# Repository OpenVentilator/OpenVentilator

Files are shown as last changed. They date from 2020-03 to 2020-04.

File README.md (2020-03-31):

# Open Ventilator
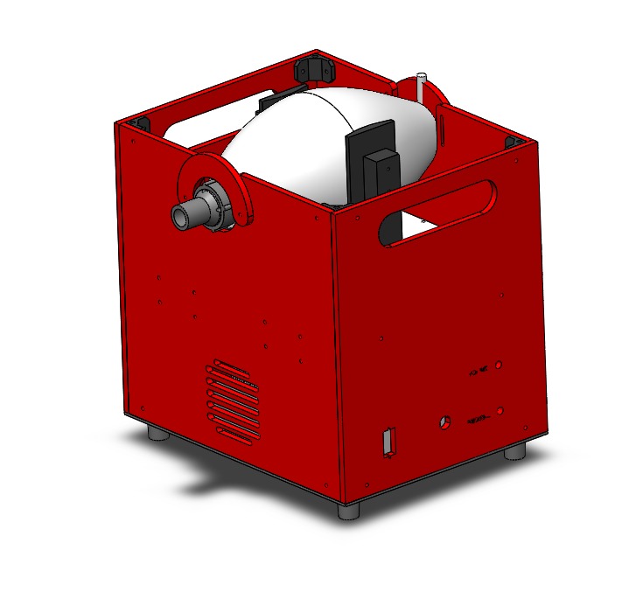
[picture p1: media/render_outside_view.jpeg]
Outside View

The open ventilator project was created in response to the demand for respirator created by the COVID-19 epidemic. The aim of the project is to create respiratory support device that can be quickly and easily produced with locally sourced material. The device is not a replacement for for respirators but in the event of a shortage of ventilators, these devices can provide support to patients that would otherwise not have any.

## Features

After consulting anesthesiologists, pulmonologists and biomedical engineers, we have settled for the below minimum feature set:

| Feature | Values |
|---|---|
| Configurable Respiratory Rate (RR) | 8-24 BPM |
| Configurable Tidal Volume (TD) | Up to 600cc |
| Configurable Fraction of Inhaled Oxygen (fio2) | Up to 100% |
| Positive End Expiratory Pressure (PEEP) | 1.5-20 H2O cm |
| Maximum Presspure | 4.0 kpa |
| Airway Pressure Monitor | 0-60 cmH2Ox |
| Exhaled air filtering | HEPA |

Several documents have been published with similar specs, notably the [Rapidly manufactured ventilator system specification published by the Department of Health and Social Care in the UK](https://www.gov.uk/government/publications/coronavirus-covid-19-ventilator-supply-specification/rapidly-manufactured-ventilator-system-specification)

### Design Approach

Our approach was to reuse existing, tested and widely available technologies where possible. We also relied on previous research done notably at MIT and Rice University to develop our design.

We settled on a BVM based design based on their availabilty and familiarity and on the available add ons that provide many of the target features.

### Air Circuit
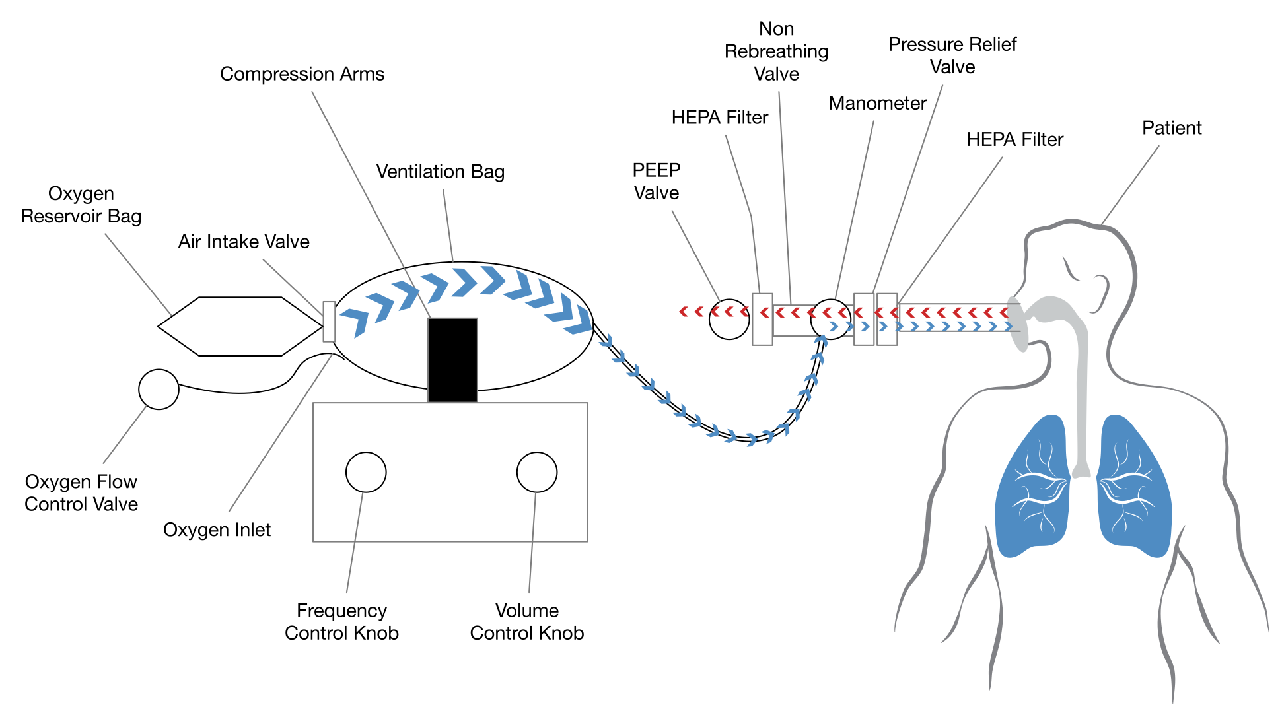
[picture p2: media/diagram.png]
Ventilator Diagram


The design in its current form implements a Mapleson A (Magill) breathing circuit. In order to achieve that, we moved the non rebreathing valve from the bag to the end of the tube. We have designed a 3D printed adaptor to connect the tube to the bag. 

### Board
To speed up go to market, we have reused an existing propriatory board we have in stock. Hence there are no schematics for the board in this repository. A dedicated open source board needs to be designed and published.

### Todo
- Publish images, renders and videos
- Publish BOM
- Design and publish logic board

### LICENSE

The design is released under a CERN Open Hardware License

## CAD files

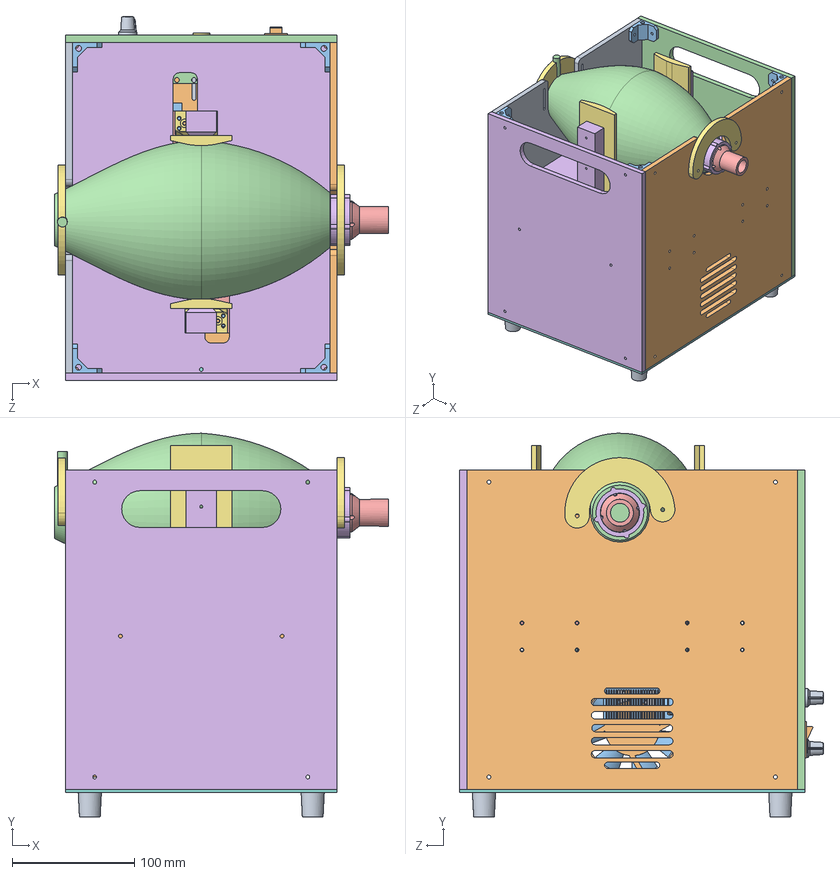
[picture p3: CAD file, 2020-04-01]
hardware/respirate_mechanism.SLDASM
273.0 x 313.3 x 297.2 mm
instrument ball bearing_68_iso x 4
motor_holder
roulement_guides x 4
limit_switch
spacerlong x 4
top_chassis_plate
pusher_holder x 2
spacershort x 4
side_cover_big
side_cover
bracket x 8
side_cover_2
spur_gear_copu x 2
side_cover_2_bis
holder_bag x 2
spur gear_iso_10 x 3
lower_gearbox_plate
Base
Cuerpo
Tapa
Eje
pusher x 2
pusher_accee x 2
lower_plate
rubber_supports x 4
Fan_HouseKD1208PTS3_KD1208PTS3
FanKD1208PTS3_KD1208PTS3
pcb
spacer15mm x 4
stepstick x 2
0402CAP_CAP0402CAP x 12
1206_CAP1206 x 2
QFN28ET_A4983 x 2
0402RES_RESISTOR0402RES x 8
0805_RESISTOR x 4
TRIMPOT3MM_TRIMPOTSMD x 2
Pin header pitch 2.54mm_08 contacts x 4
Heatsink For A4988 x 2
Motor Driver x 3
atmega2560
tactile_switch_smd
resonator16mhz
connector_8_pins x 3
connector_2_pins x 4
connector_5_pins x 3
connector_6_pins
connector_3_pins x 6
connector_4_pins x 5
pan head cross recess screw_iso x 4
mks-tb6600
AMBU_BAG
ambu_adaptor_part1
ambu_adaptor_part2
dc_connector
Knob-4 x 2
switch

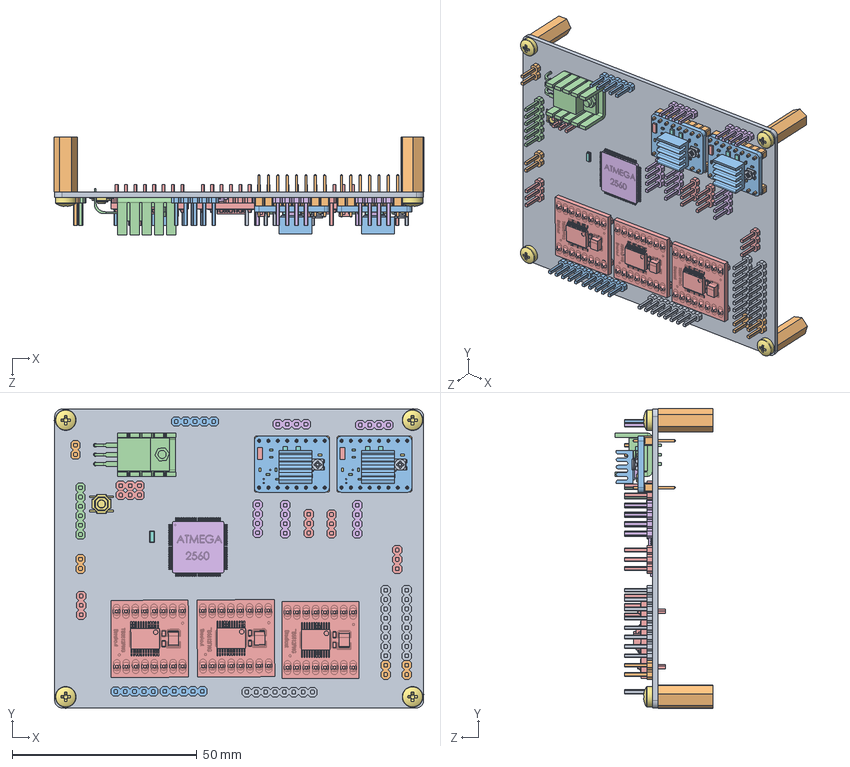
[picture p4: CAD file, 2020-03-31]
hardware/board.SLDASM
100.3 x 81.3 x 26.7 mm
pcb
spacer15mm x 4
stepstick x 2
0402CAP_CAP0402CAP x 12
1206_CAP1206 x 2
QFN28ET_A4983 x 2
0402RES_RESISTOR0402RES x 8
0805_RESISTOR x 4
TRIMPOT3MM_TRIMPOTSMD x 2
Pin header pitch 2.54mm_08 contacts x 4
Heatsink For A4988 x 2
Motor Driver x 3
atmega2560
tactile_switch_smd
resonator16mhz
connector_8_pins x 3
connector_2_pins x 4
connector_5_pins x 3
connector_6_pins
connector_3_pins x 6
connector_4_pins x 5
pan head cross recess screw_iso x 4

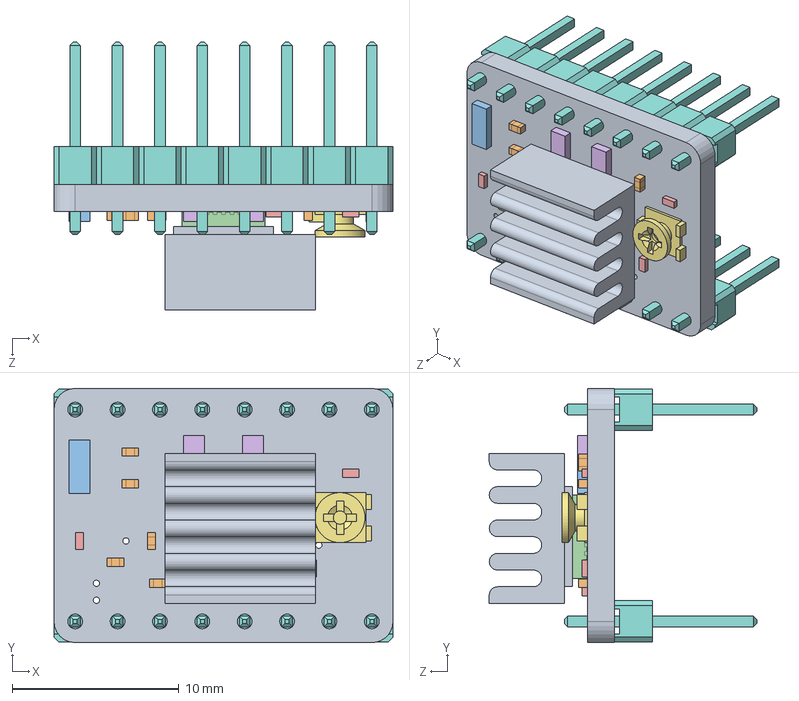
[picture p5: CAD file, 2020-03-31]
hardware/stepper_motor_driver.SLDASM
20.3 x 15.2 x 16.0 mm
stepstick
0402CAP_CAP0402CAP x 6
1206_CAP1206
QFN28ET_A4983
0402RES_RESISTOR0402RES x 4
0805_RESISTOR x 2
TRIMPOT3MM_TRIMPOTSMD
Pin header pitch 2.54mm_08 contacts x 2
Heatsink For A4988

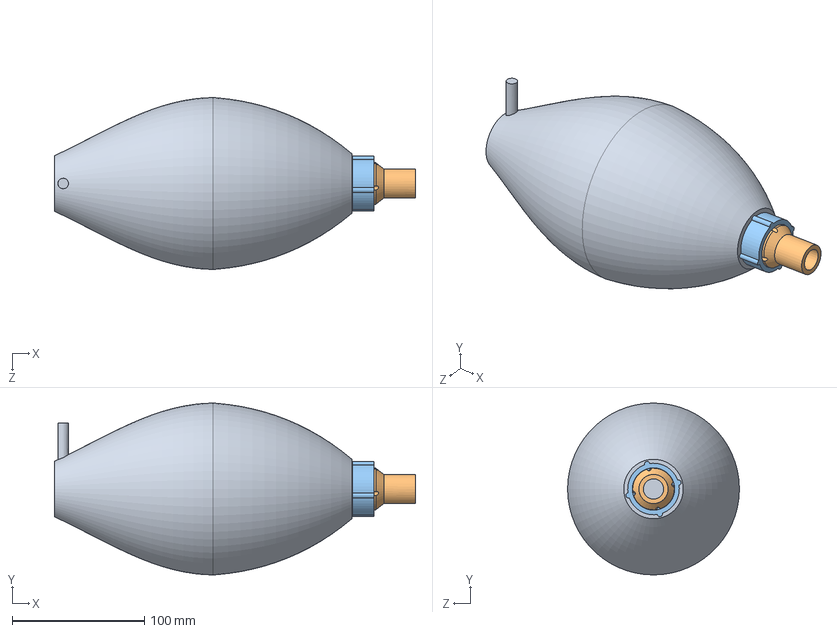
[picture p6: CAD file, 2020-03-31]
hardware/AMBU_Assembly.SLDASM
273.0 x 130.0 x 130.0 mm
AMBU_BAG
ambu_adaptor_part1
ambu_adaptor_part2

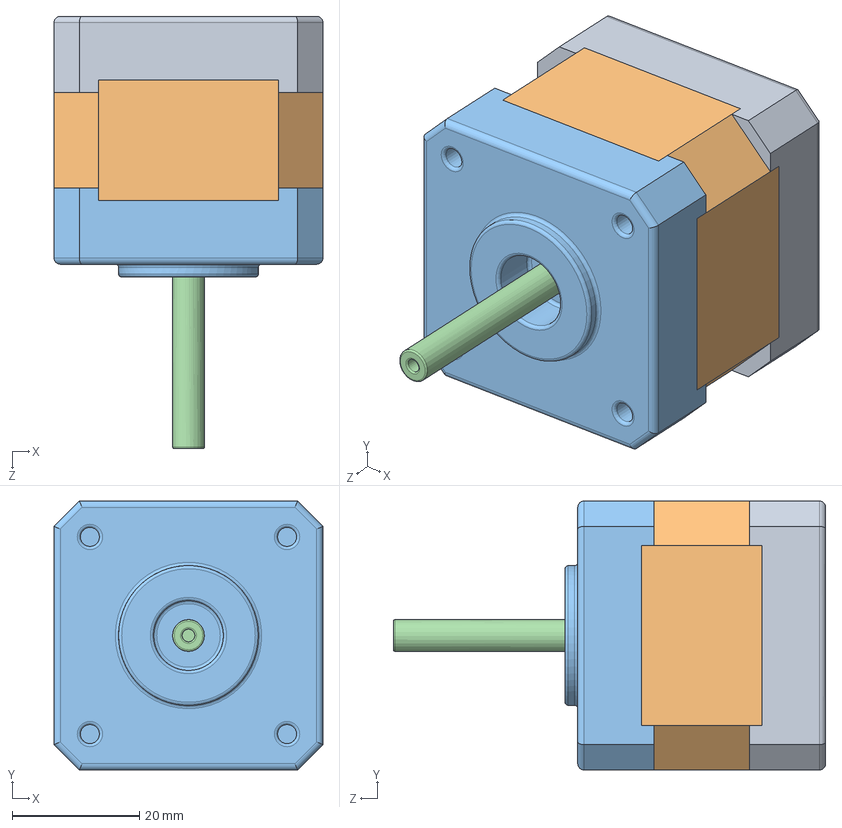
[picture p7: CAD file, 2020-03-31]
hardware/NEMA 17 with T5 Pulley.SLDASM
42.3 x 42.3 x 68.0 mm
Base
Cuerpo
Tapa
Eje

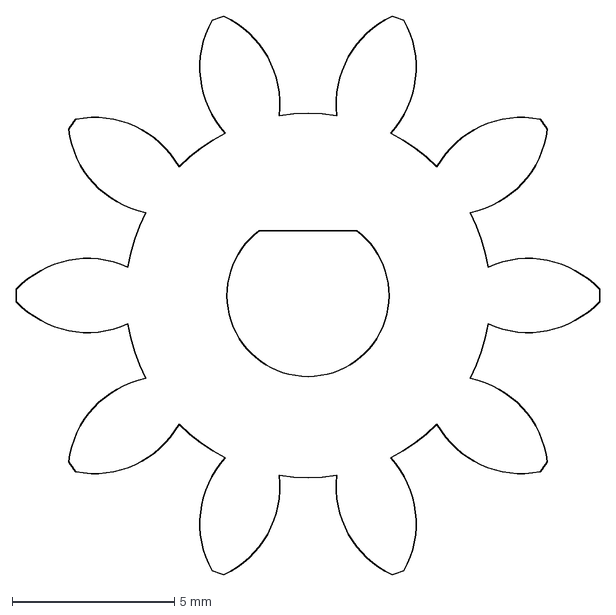
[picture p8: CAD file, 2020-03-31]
hardware/Gears_DXF/spur_gear_10X2.DXF
18.0 x 17.2 mm

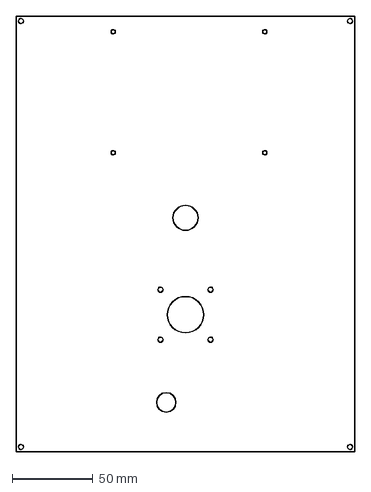
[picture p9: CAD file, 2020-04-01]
hardware/PLEXI_DXF/lower_gearbox_plate.DXF
210.0 x 270.0 mm

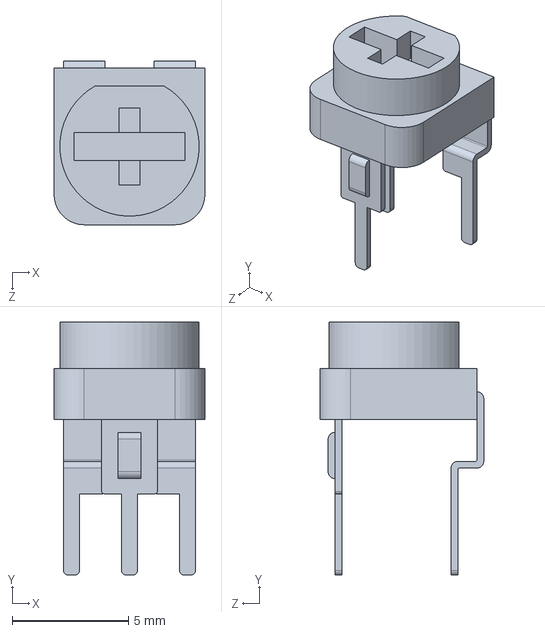
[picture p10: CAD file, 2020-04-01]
hardware/Pot - RES_VAR1.sldprt
6.50 x 10.9 x 7.05 mm

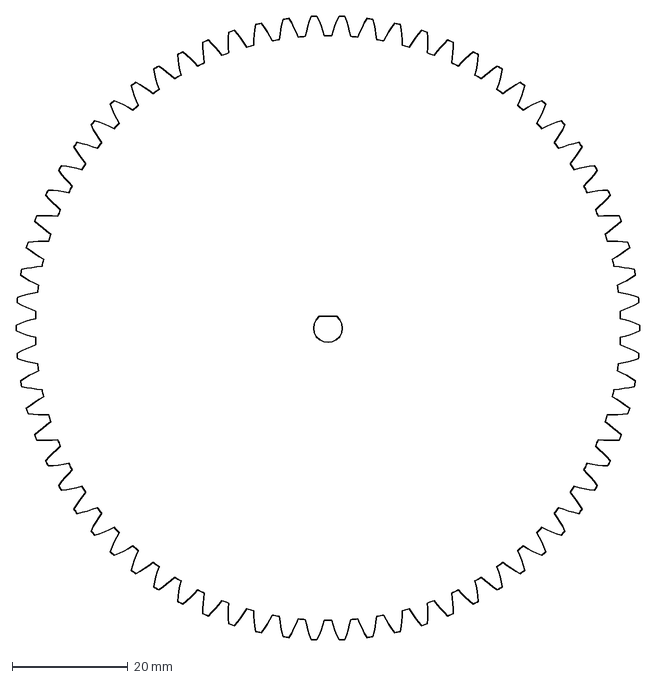
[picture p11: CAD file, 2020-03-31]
hardware/Gears_DXF/spur_gear_70.DXF
108.0 x 107.9 mm

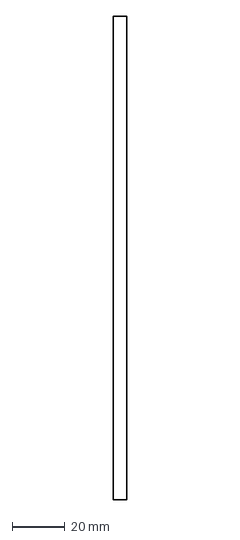
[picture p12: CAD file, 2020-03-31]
hardware/PLEXI_DXF/roulement_guides_slim.DXF
5.21 x 182.6 mm

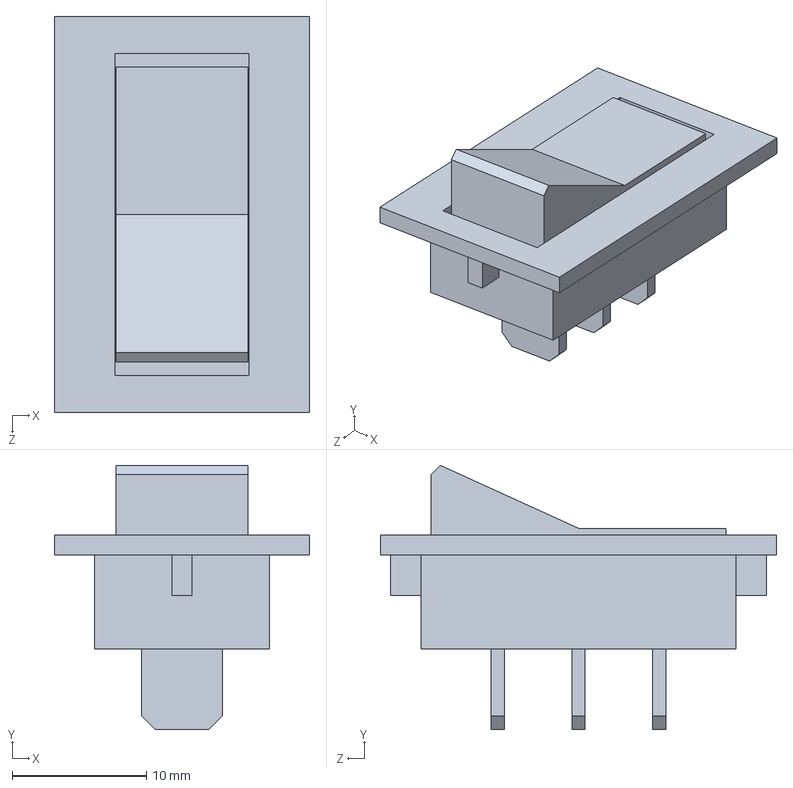
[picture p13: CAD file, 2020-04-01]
hardware/switch.SLDPRT
19.0 x 19.7 x 29.5 mm

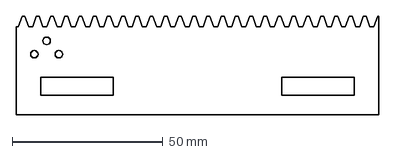
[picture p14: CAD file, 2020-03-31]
hardware/Gears_DXF/rackX2.DXF
120.0 x 32.5 mm

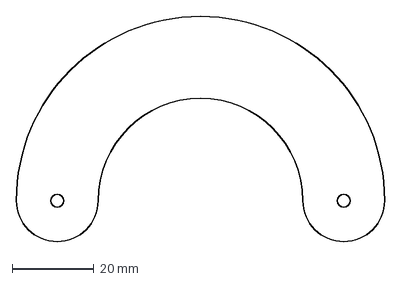
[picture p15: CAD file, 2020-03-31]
hardware/PLEXI_DXF/holder_bag.DXF
90.0 x 55.0 mm

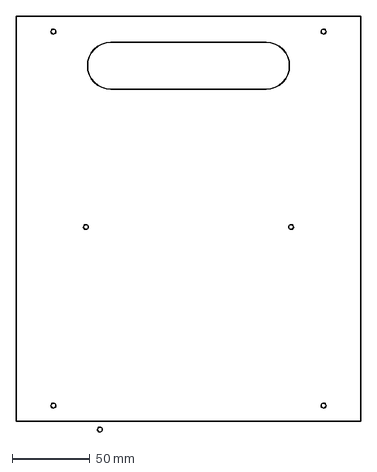
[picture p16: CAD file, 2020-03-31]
hardware/PLEXI_DXF/side_cover_2_bis.DXF
222.0 x 267.7 mm

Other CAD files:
hardware/Knob-4.sldprt
hardware/PLEXI_DXF/lower_plate.DXF
hardware/lower_gearbox_plate.SLDPRT
hardware/PLEXI_DXF/side_cover.DXF
hardware/0402CAP_CAP0402CAP.sldprt
hardware/0402RES_RESISTOR0402RES.sldprt
hardware/0805_RESISTOR.sldprt
hardware/1206_CAP1206.sldprt
hardware/67898.SLDPRT
hardware/7805.SLDPRT
hardware/AMBU_BAG.SLDPRT
hardware/Base.SLDPRT
hardware/Cuerpo.SLDPRT
hardware/Eje.SLDPRT
hardware/FanKD1208PTS3_KD1208PTS3.sldprt
hardware/Fan_HouseKD1208PTS3_KD1208PTS3.sldprt
hardware/Heatsink For A4988.sldprt
hardware/KD1208PTS3.SLDASM
hardware/KD1208PTS3.step
hardware/Motor Driver.SLDPRT
hardware/PLEXI_DXF/motor_holder.DXF
hardware/PLEXI_DXF/roulement_guides.DXF
hardware/PLEXI_DXF/side_cover_2.DXF
hardware/PLEXI_DXF/side_cover_big.DXF
hardware/PLEXI_DXF/spacerlong.DXF
hardware/PLEXI_DXF/spacershort.DXF
hardware/PLEXI_DXF/top_chassis_plate.DXF
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

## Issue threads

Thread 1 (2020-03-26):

Reinforce arms platform

OpenVentilator, 2020-03-26:
As suggested by Paul Abi Nasr on this slack thread, time fatigue might break this piece and needs to be reinforced.

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

https://nerds-leb.slack.com/archives/C01013DQRHQ/p1585160358016100

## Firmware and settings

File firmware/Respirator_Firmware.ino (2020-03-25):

#include <Stepper.h>
#include <EEPROM.h>
#include <math.h>
#include "STEPPER.H"

///////////////Stepper///////////////// 
STEPPER _S   = {1,22,LOW,24,LOW,25,16,0,0,480,0};          
///////////////Stepper/////////////////

int show_logs = HIGH;

int frequency_pin = A1;
int freq = 0;
int Volume_pin = A0;
int vol = 0;

int max_travel = 3500;
int min_travel = 600;

void setup() 
{
    Serial.begin(9600); 
    _init_steppers();
    home_stepper(&_S,_S._speed,_S._speed);  

    freq  = read_frequency_knob () ; 
    vol = read_volume_knob ();
     
    Serial.print("VOLUME: "); Serial.println(read_volume_knob ());
    Serial.print("FREQ: "); Serial.println(read_frequency_knob ());
    delay(50);
}


void test_stepper()
{
    if(Serial.available()>0)
    {
         int x = Serial.parseInt();
       
         if ( x >=0 )
         {
             run_stepper( &_S,  x );
         }
         else 
         {
             home_stepper(&_S, _S._speed ,_S._speed/2);
         }

         while (Serial.available()>0)
         {
             Serial.read();
         }
    }
}

void loop() 
{    
     freq  = read_frequency_knob () ; 
     vol = read_volume_knob ();
     
     Serial.print("VOLUME: "); Serial.println(read_volume_knob ());
     Serial.print("FREQ: "); Serial.println(read_frequency_knob ());
     delay(50);

           
     long timer1 = millis();
     if(vol ==1 ) run_stepper( &_S,  max_travel - 300 );
     else if (vol == 2 ) run_stepper( &_S,  max_travel - 150 );
     else run_stepper( &_S,  max_travel );  
     run_stepper( &_S,  min_travel);
     long timer2 = millis() - timer1;
     Serial.print("Timer: ");Serial.println(timer2 );

     calculate_delay_and_wait( freq , timer2 );
}

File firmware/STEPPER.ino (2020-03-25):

void _init_steppers()
{
    pinMode( _S._en_pin , OUTPUT);
    pinMode( _S._dir_pin , OUTPUT);
    pinMode( _S._pulse_pin , OUTPUT);
    digitalWrite( _S._en_pin , _S._en);
    digitalWrite( _S._dir_pin, _S._dir);
    digitalWrite( _S._pulse_pin , LOW);
    pinMode(  _S._limit_switch_pin , INPUT_PULLUP );

    update_stepper_speed(&_S);
}

int instant_check_limit_switch(STEPPER *S)
{
    if( digitalRead(S->_limit_switch_pin) == LOW ) return 1; 
    else return 0;
}

int check_limit_switch(STEPPER *S, int _dt)
{
    if( get_input(S->_limit_switch_pin, _dt) == LOW ) return 1; 
    else return 0;
}


void print_stepper_info(STEPPER *S)
{ 
    Serial.print("Enable: "); Serial.println(S->_en); 
    Serial.print("Direction: "); Serial.println(S->_dir); 
    Serial.print("Steps: "); Serial.println(S->_steps_actual); 
    Serial.print("Speed: "); Serial.println(S->_speed); 
}


long convert_speed_to_delay( int s)
{
    return  round (100000 / s) ; 
}

void update_stepper_direction(STEPPER *S)
{
    digitalWrite( S->_dir_pin , S->_dir);
}

void update_enable(STEPPER *S)
{
    digitalWrite( S->_en_pin, S->_en);
}


void update_stepper_speed(STEPPER *S)
{
      S->_cs = convert_speed_to_delay( S->_speed);
}

void update_stepper_speed(STEPPER *S, int sss)
{
      S->_speed= sss;
      S->_cs = convert_speed_to_delay( S->_speed);
}
  


void pulse_stepper( STEPPER *S)
{
    digitalWrite(S->_pulse_pin,HIGH);
    delayMicroseconds(S->_cs);
    digitalWrite(S->_pulse_pin,LOW);
    delayMicroseconds( S->_cs); 

    if( S->_dir == HIGH ) S->_steps_actual ++ ;
    else if( S->_dir == LOW ) S->_steps_actual --;
}

void home_stepper(STEPPER *S, int Vmax , int Vmin)
{
    int old_speed = S->_speed ; 
    
    S->_en = HIGH; 
    update_enable(S);
    
    S->_dir = LOW ;
    S->_speed = Vmax;
    update_stepper_speed(S); 
    update_stepper_direction(S);
    
    while(  true)
    {      
        if(  instant_check_limit_switch(S) == 1 )
        {
              S->_steps_actual = 0;
              break;
        }
    
        pulse_stepper(S);
    }
    
    delay(50);
    
    S->_speed  =  old_speed ;
    update_stepper_speed(S);

    S->_en = LOW; 
    update_enable(S);
    
} 

void run_stepper( STEPPER *S , long stp_desired)
{ 
    S->_steps_desired = stp_desired;
    long delta_steps = S->_steps_desired - S->_steps_actual ;

    if(delta_steps >0 ) S->_dir = HIGH;
    else if( delta_steps <0 ) S->_dir = LOW;

    S->_en =HIGH; 
    update_enable(S);
    update_stepper_direction(S);

    while( true )
    {
         delta_steps = S->_steps_desired- S->_steps_actual ;
         if( delta_steps == 0 )
         {
             if( show_logs == HIGH )
             {
                  Serial.print("MVT DONE"); Serial.println( S->_steps_actual);
             }
             break;
         }
         
         pulse_stepper(S);
    }   

    S->_en = LOW; 
    update_enable(S);
}


void run_stepper( STEPPER *S , long stp_desired , int brake)
{ 
    S->_en = LOW; 
    update_enable(S);
    
    S->_steps_desired = stp_desired;
    long delta_steps = S->_steps_desired - S->_steps_actual ;

    if(delta_steps >0 ) S->_dir = HIGH;
    else if( delta_steps <0 ) S->_dir = LOW;

    if( S->id == 1 ) S->_en = HIGH; 
    else S->_en = LOW ; 
    update_enable(S);
    
    update_stepper_direction(S);

    while( true )
    {
         delta_steps = S->_steps_desired- S->_steps_actual ;
         if( delta_steps == 0 )
         {
             if( show_logs == HIGH )
             {
                  Serial.print("MVT DONE"); Serial.println( S->_steps_actual);
             }
             break;
         }
         
         pulse_stepper(S);
    }    

    if ( brake == LOW )
    {
        if( S->id == 1 ) S->_en = LOW; 
        else S->_en = HIGH ; 
        update_enable(S);
    }
    else if( brake == HIGH )
    {
        if( S->id == 1 ) S->_en = HIGH; 
        else S->_en = LOW ; 
        update_enable(S);
    }

}

void run_stepper( STEPPER *S , long steps_d , int sp , int dd , int brake)
{ 
    S->_dir = dd;
    S->_speed = sp;
    update_stepper_speed(S);
    
    if( dd == HIGH)  S->_steps_desired =  S->_steps_actual + steps_d  ;
    else if (dd == LOW)  S->_steps_desired = S->_steps_actual -steps_d  ;

    S->_en = LOW;
    update_enable(S);
    update_stepper_direction(S);

    while( true )
    {
         if( S->_steps_actual == S->_steps_desired )
         {
             if( show_logs == HIGH ) 
             {
                  Serial.print("MVT DONE "); Serial.println( S->_steps_actual);
             }
             break;
         }
         
         pulse_stepper(S);        
    }    


    if( brake == LOW )
    {
        S->_en = HIGH;
        update_enable(S);
    }
    else if( brake == HIGH )
    {
        S->_en = LOW ;
        update_enable(S);
    }
  
}


void run_stepper_3( STEPPER *S , long stp  )
{ 
    if(S->_dir ==HIGH) S->_steps_desired = stp + S->_steps_actual ;
    else S->_steps_desired = - stp + S->_steps_actual ;
    long delta_steps = S->_steps_desired - S->_steps_actual ;

    S->_en = LOW;
    update_enable(S);

    while( true )
    {
         delta_steps = S->_steps_desired - S->_steps_actual ;

         if( delta_steps == 0 )
         {
             if( show_logs == HIGH )
             {
                 Serial.print("MVT DONE"); Serial.println( S->_steps_actual);
             }
             break;
         }
         
         pulse_stepper(S);
    }    

    S->_en = HIGH;
    update_enable(S);
    
}

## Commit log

2020-03-25 initatl commit
    [0402CAP_CAP0402CAP.sldprt, 0402RES_RESISTOR0402RES.sldprt, 0805_RESISTOR.sldprt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]
2020-03-31 updated designs
    [AMBU_Assembly.SLDASM, AMBU_BAG.SLDPRT, KD1208PTS3.SLDASM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]
2020-04-01 Updated designs with on-off switch
    [67898.SLDPRT, Knob-4.sldprt, Pot - RES_VAR1.sldprt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]
